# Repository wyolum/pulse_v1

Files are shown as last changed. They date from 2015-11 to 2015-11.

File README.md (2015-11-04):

# pulse_v1
Breathing LED lamp for Motorcycle using ATtiny
=======

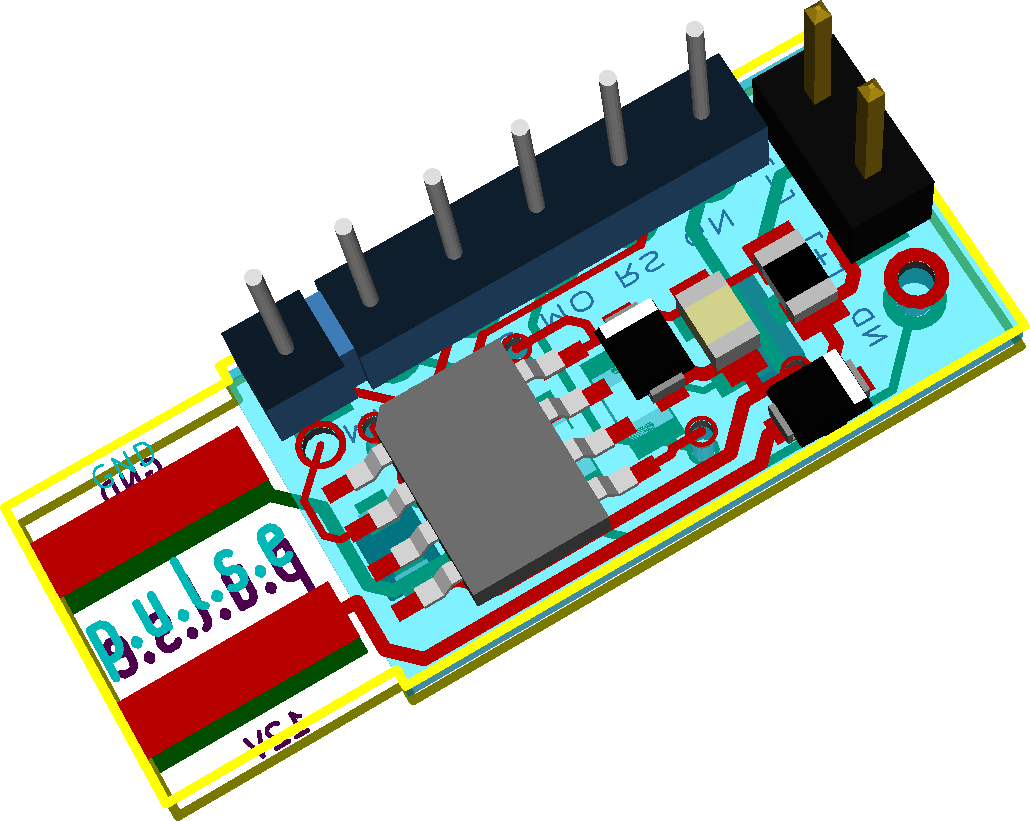
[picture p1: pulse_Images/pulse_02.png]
pulse_v1 top


License
-------
[CERN Open Hardware Licence v1.2 ]

[CERN Open Hardware Licence v1.2 ]:http://www.ohwr.org/attachments/2388/cern_ohl_v_1_2.txt

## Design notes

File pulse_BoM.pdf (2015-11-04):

BoM, for kit building assembly | 5.05 | 4.54
ref | value | MODULE | Manufacturer | Mfr. P/N | Vendor | Vendor P/N | NOTE1 | QTY | RATE | AMOUNT
C1 | 10n | c_0805 | Kemet | C0805C103K5RACTU | 399-1158-1-ND | Decoupling capacitor, Ceramic | 1 0.05 | 0.05
C2 | 100n | c_0805 | Kemet | C0805C104K3RACTU | 399-1168-1-ND | Decoupling capacitor, Ceramic | 1 0.07 | 0.07
D1 | Z5V1 | SOD323F | Fairchild Semiconductor | MM3Z5V1C | MM3Z5V1CCT-ND | input protection diode | 1 0.20 | 0.20
D2 | Z5V1 | SOD323F | Fairchild Semiconductor | MM3Z5V1C | MM3Z5V1CCT-ND | 5V regulation diode | 1 0.20 | 0.20
D3 | 1N4448WT | SOD523F | Fairchild Semiconductor | 1N4448WT | | 1N4448WTCT-ND | reverse polarity protection diode | 1 | 0.17 | 0.17
K2 | ISP | pin_strip_6b Sullins Connector Solutions PREC040SAAN-RC | S1012EC-40-ND | Header, Male, 8x1 – K2+P1+P3 | 1 | 0.51 | 0.00
P1 | LAMP | pin_strip_2 | -- | -- | -- | -- | PCB edge fits Lamp T10 connector | 1 0.00 | 0.00
P2 | 12V | Header_12V -- | -- | -- | -- | see K2 | 1 0.00 | 0.00
P3 | ND | Pad01 | -- | -- | -- | -- | see K2 | 1 0.00 | 0.00
PB3 ND | Pad01 | -- | -- | -- | -- | breakout pad | 1 0.00 | 0.00
PCB1 PCB | PCB | seeed | -- | -- | -- | -- | 1 | 2.38 | 2.38
Q1 | 2N7000 | SOT23-3 | Toshiba | SSM3K7002BF(T5L,F) | SSM3K7002BF(T5LF)CT-ND | 1 0.35 | 0.35
R1 | 4K7 | r_0805 | Stackpole Electronics Inc | RMCF0805JT4K70 | RMCF0805JT4K70CT-ND | 1 0.03 | 0.03
R2 | 4K7 | r_0805 | Stackpole Electronics Inc | RMCF0805JT4K70 | RMCF0805JT4K70CT-ND | 1 0.03 | 0.03
R3 | 2k2 | r_0805 | Stackpole Electronics Inc | RMCF0805JT2K20 | RMCF0805JT2K20CT-ND | 1 0.03 | 0.03
U1 | ATTINY45-20SUSO8E | Atmel | ATTINY45-20SU | ATTINY45-20SU-ND | 1 | 1.03 | 1.03

DigiKey (http://www.digikey.com/product-detail/en/C0805C103K5RACTU/399-1158-1-ND/411433)
DigiKey (http://www.digikey.com/product-detail/en/C0805C104K3RACTU/399-1168-1-ND/411443)
DigiKey
DigiKey (http://www.digikey.com/product-detail/en/MM3Z5V1C/MM3Z5V1CCT-ND/1626900)
DigiKey (http://www.digikey.com/product-detail/en/1N4448WT/1N4448WTCT-ND/1966596)
DigiKey (http://www.digikey.com/product-detail/en/PREC040SAAN-RC/S1012EC-40-ND/2774814)

DigiKey (http://www.digikey.com/product-detail/en/SSM3K7002BF(T5L,F)/SSM3K7002BF(T5LF)CT-ND/969393)
DigiKey
DigiKey (http://www.digikey.com/product-detail/en/RMCF0805JT4K70/RMCF0805JT4K70CT-ND/1942570)
DigiKey (http://www.digikey.com/product-detail/en/RMCF0805JT2K20/RMCF0805JT2K20CT-ND/1942563)
DigiKey (http://www.digikey.com/product-detail/en/ATTINY45-20SU/ATTINY45-20SU-ND/735466)

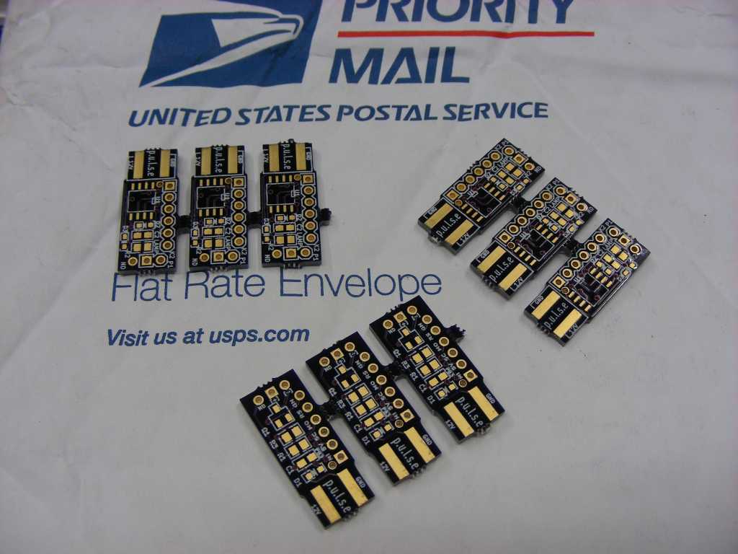
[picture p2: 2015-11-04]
pulse_Images/pulse_03.jpg

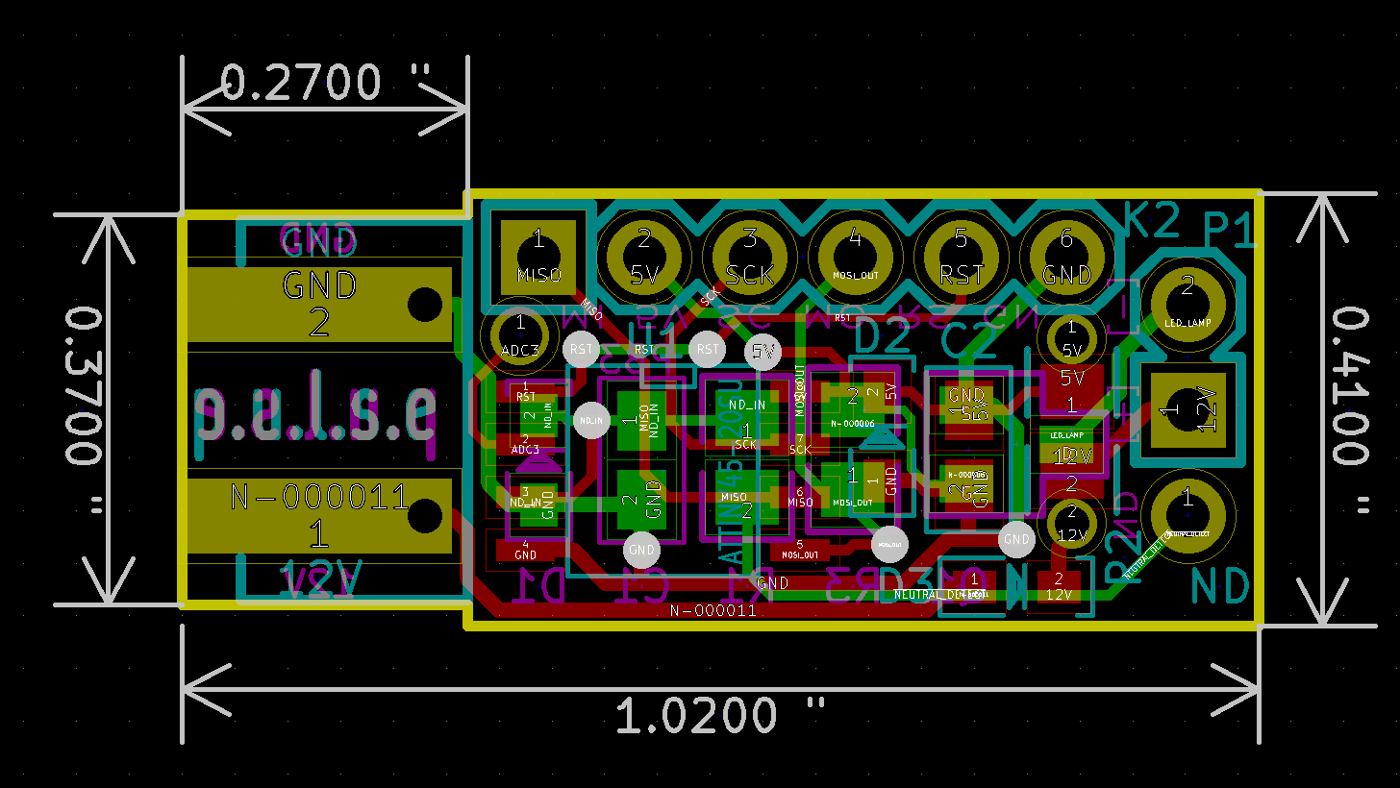
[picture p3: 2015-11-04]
pulse_Images/pulse_01.png

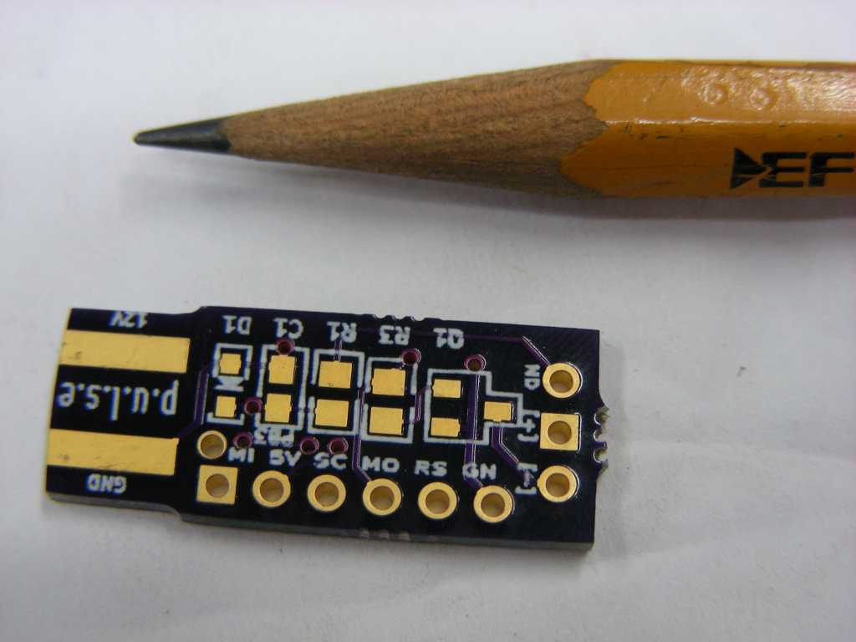
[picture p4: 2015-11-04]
pulse_Images/pulse_05.jpg

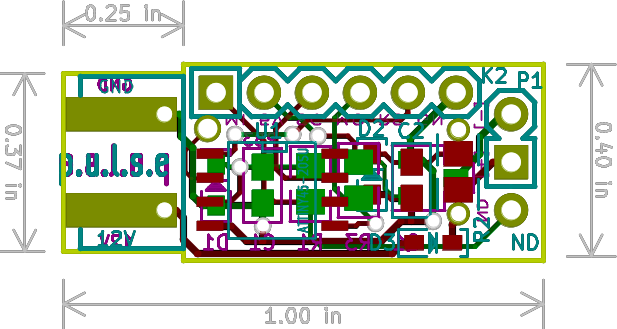
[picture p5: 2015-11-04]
pulse_Images/pulse_v1_PCB_stack.png

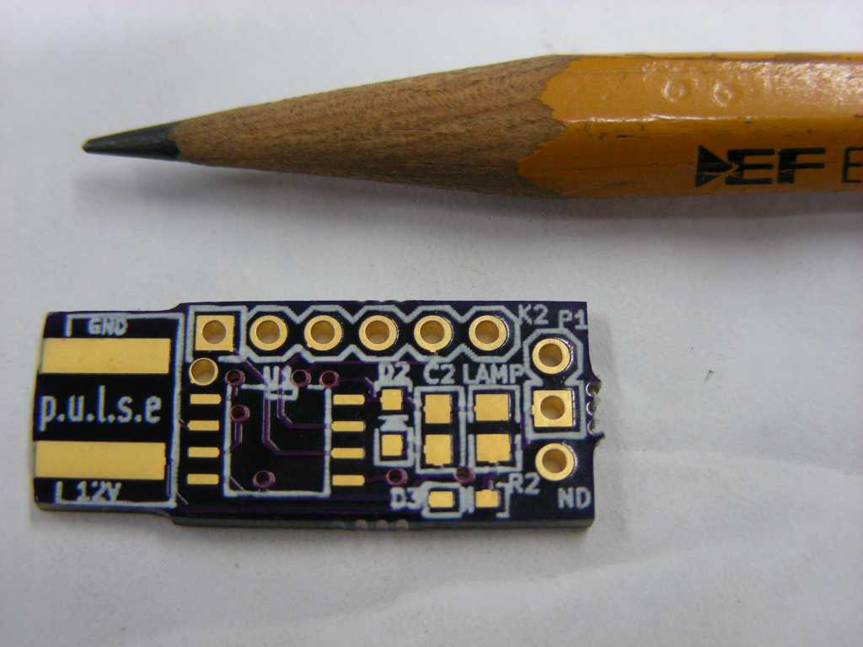
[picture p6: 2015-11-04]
pulse_Images/pulse_04.jpg

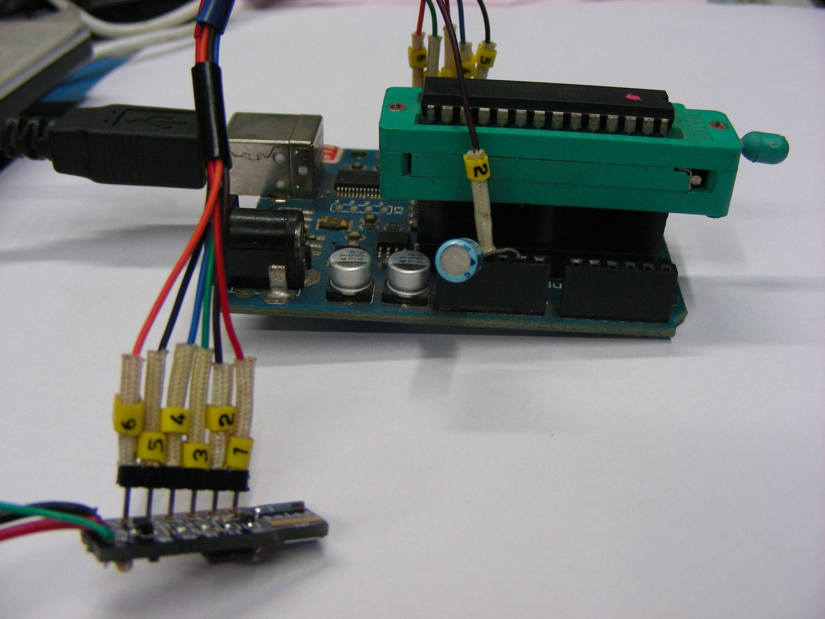
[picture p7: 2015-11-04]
pulse_Images/pulse_09.jpg

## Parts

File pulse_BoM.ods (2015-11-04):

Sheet: Final_BoM
BoM, for kit building assembly |  |  |  |  |  |  |  |  | 5.05 | 4.54
ref | value | MODULE | Manufacturer | Mfr. P/N | Vendor | Vendor P/N | NOTE1 | QTY | RATE | AMOUNT
C1 | 10n | c_0805 | Kemet | C0805C103K5RACTU | DigiKey (http://www.digikey.com/product-detail/en/C0805C103K5RACTU/399-1158-1-ND/411433) | 399-1158-1-ND | Decoupling capacitor, Ceramic | 1 | 0.05 | 0.05
C2 | 100n | c_0805 | Kemet | C0805C104K3RACTU | DigiKey (http://www.digikey.com/product-detail/en/C0805C104K3RACTU/399-1168-1-ND/411443) | 399-1168-1-ND | Decoupling capacitor, Ceramic | 1 | 0.07 | 0.07
D1 | Z5V1 | SOD323F | Fairchild Semiconductor | MM3Z5V1C | DigiKey (http://www.digikey.com/product-detail/en/MM3Z5V1C/MM3Z5V1CCT-ND/1626900) | MM3Z5V1CCT-ND | input protection diode | 1 | 0.20 | 0.20
D2 | Z5V1 | SOD323F | Fairchild Semiconductor | MM3Z5V1C | DigiKey (http://www.digikey.com/product-detail/en/MM3Z5V1C/MM3Z5V1CCT-ND/1626900) | MM3Z5V1CCT-ND | 5V regulation diode | 1 | 0.20 | 0.20
D3 | 1N4448WT | SOD523F | Fairchild Semiconductor | 1N4448WT | DigiKey (http://www.digikey.com/product-detail/en/1N4448WT/1N4448WTCT-ND/1966596) | 1N4448WTCT-ND | reverse polarity protection diode | 1 | 0.17 | 0.17
K2 | ISP | pin_strip_6b | Sullins Connector Solutions | PREC040SAAN-RC | DigiKey (http://www.digikey.com/product-detail/en/PREC040SAAN-RC/S1012EC-40-ND/2774814) | S1012EC-40-ND | Header, Male, 8x1 – K2+P1+P3 | 1 | 0.51 | 0.00
P1 | LAMP | pin_strip_2 | -- | -- | -- | -- | PCB edge fits Lamp T10 connector | 1 | 0.00 | 0.00
P2 | 12V | Header_12V | -- | -- | -- | -- | see K2 | 1 | 0.00 | 0.00
P3 | ND | Pad01 | -- | -- | -- | -- | see K2 | 1 | 0.00 | 0.00
PB3 | ND | Pad01 | -- | -- | -- | -- | breakout pad | 1 | 0.00 | 0.00
PCB1 | PCB | PCB | seeed | -- | -- | -- | -- | 1 | 2.38 | 2.38
Q1 | 2N7000 | SOT23-3 | Toshiba | SSM3K7002BF(T5L,F) | DigiKey (http://www.digikey.com/product-detail/en/SSM3K7002BF(T5L,F)/SSM3K7002BF(T5LF)CT-ND/969393) | SSM3K7002BF(T5LF)CT-ND |  | 1 | 0.35 | 0.35
R1 | 4K7 | r_0805 | Stackpole Electronics Inc | RMCF0805JT4K70 | DigiKey (http://www.digikey.com/product-detail/en/RMCF0805JT4K70/RMCF0805JT4K70CT-ND/1942570) | RMCF0805JT4K70CT-ND |  | 1 | 0.03 | 0.03
R2 | 4K7 | r_0805 | Stackpole Electronics Inc | RMCF0805JT4K70 | DigiKey (http://www.digikey.com/product-detail/en/RMCF0805JT4K70/RMCF0805JT4K70CT-ND/1942570) | RMCF0805JT4K70CT-ND |  | 1 | 0.03 | 0.03
R3 | 2k2 | r_0805 | Stackpole Electronics Inc | RMCF0805JT2K20 | DigiKey (http://www.digikey.com/product-detail/en/RMCF0805JT2K20/RMCF0805JT2K20CT-ND/1942563) | RMCF0805JT2K20CT-ND |  | 1 | 0.03 | 0.03
U1 | ATTINY45-20SU | SO8E | Atmel | ATTINY45-20SU | DigiKey (http://www.digikey.com/product-detail/en/ATTINY45-20SU/ATTINY45-20SU-ND/735466) | ATTINY45-20SU-ND |  | 1 | 1.03 | 1.03

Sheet: BoM_SCH
ref | value | footprint | Field1 | Field2 | Field3 | Field4 | Field5 | Field6 | Field7 | Field8
C1 | 10n | c_0805
C2 | 100n | c_0805
D1 | Z5V1 | SOD323F
D2 | Z5V1 | SOD323F
D3 | 1N4448WT | SOD523F
K2 | ISP | pin_strip_6b
P1 | LAMP | pin_strip_2
P2 | 12V | Header_12V
P3 | ND | Pad01
PB3 | ND | Pad01
PCB1 | PCB | PCB
Q1 | 2N7000 | SOT23-3
R1 | 4K7 | r_0805
R2 | 4K7 | r_0805
R3 | 2k2 | r_0805
U1 | ATTINY45-20SU | SO8E

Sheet: BoM_PCB
Id | Designator | Package | Quantity | Designation | Supplier and ref
1 | C1 | c_0805 | 1 | 10n
2 | C2 | c_0805 | 1 | 100n
3 | D1,D2 | SOD323F | 2 | Z5V1
4 | D3 | SOD523F | 1 | 1N4448WT
5 | K2 | pin_strip_6b | 1 | ISP
6 | P1 | pin_strip_2 | 1 | LAMP
7 | P2 | Header_12V | 1 | 12V
8 | P3,PB3 | Pad01 | 1 | ND
9 | PCB1 | PCB | 1 | PCB
10 | Q1 | SOT23-3 | 1 | 2N7000
11 | R1,R2 | r_0805 | 2 | 4K7
12 | R3 | r_0805 | 1 | 2k2
13 | U1 | SO8E | 1 | ATTINY45-20SU

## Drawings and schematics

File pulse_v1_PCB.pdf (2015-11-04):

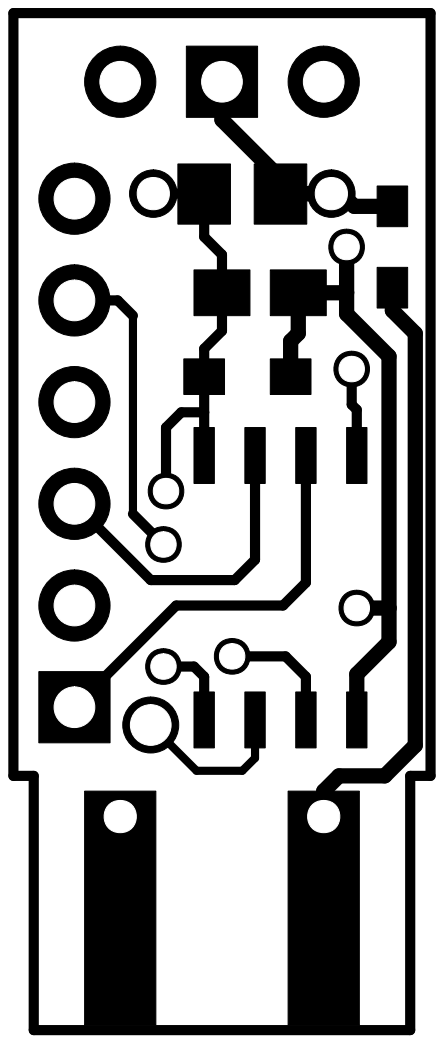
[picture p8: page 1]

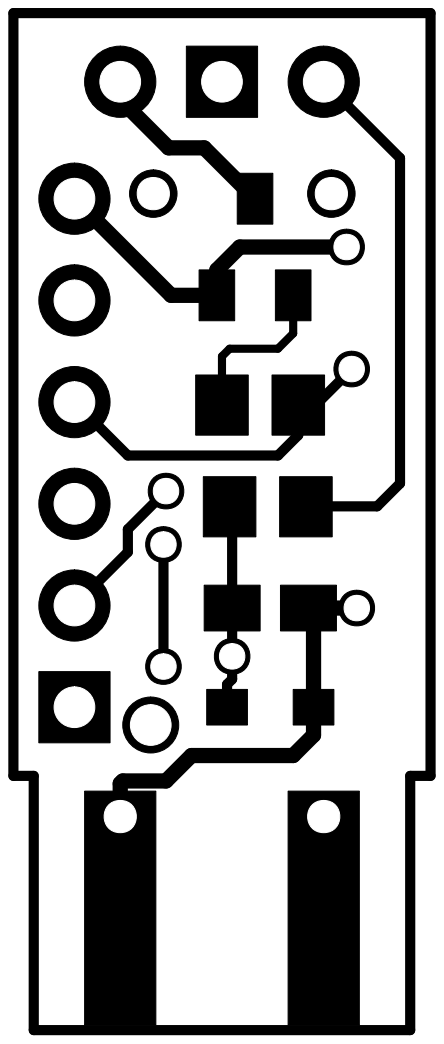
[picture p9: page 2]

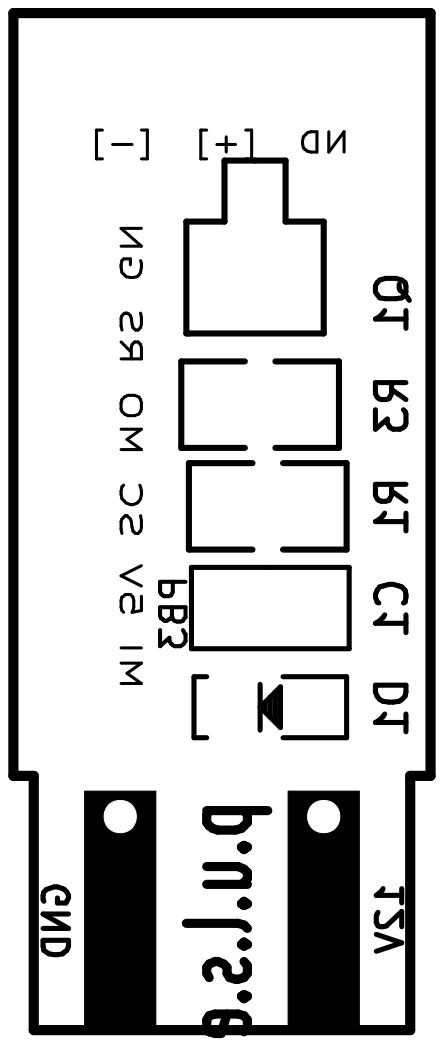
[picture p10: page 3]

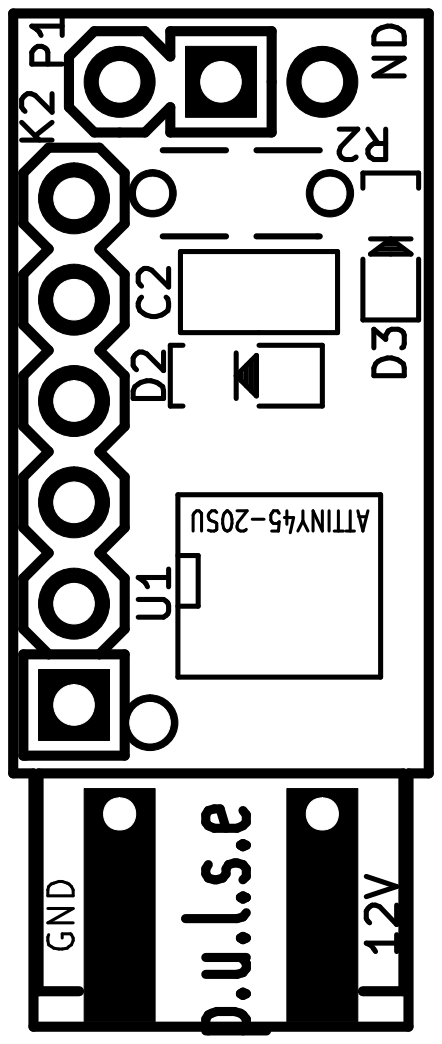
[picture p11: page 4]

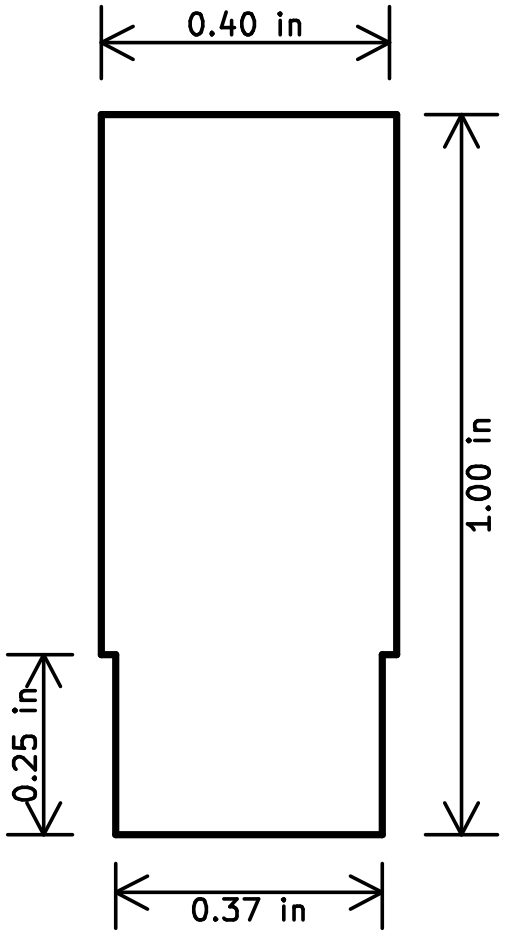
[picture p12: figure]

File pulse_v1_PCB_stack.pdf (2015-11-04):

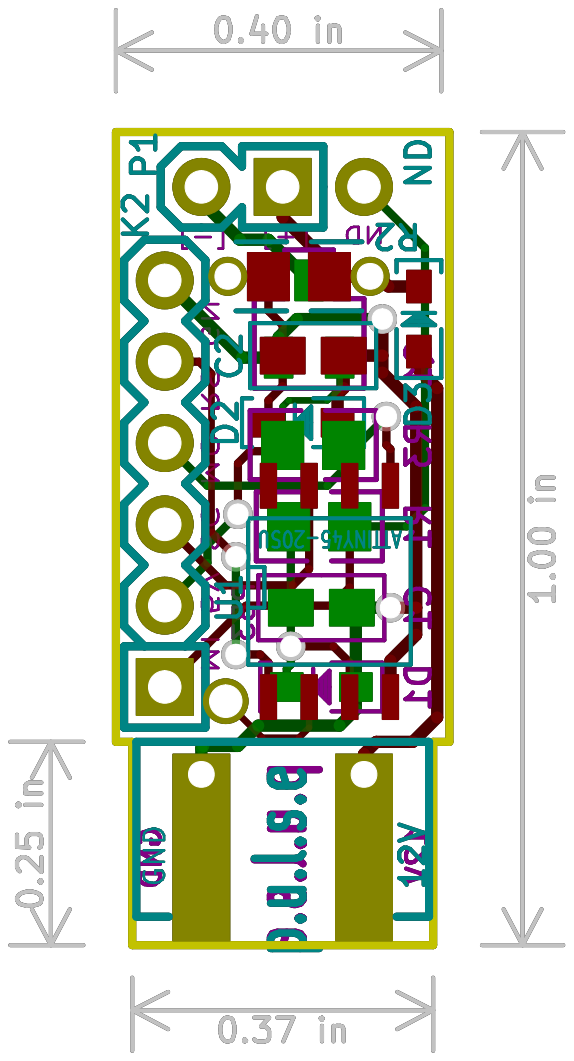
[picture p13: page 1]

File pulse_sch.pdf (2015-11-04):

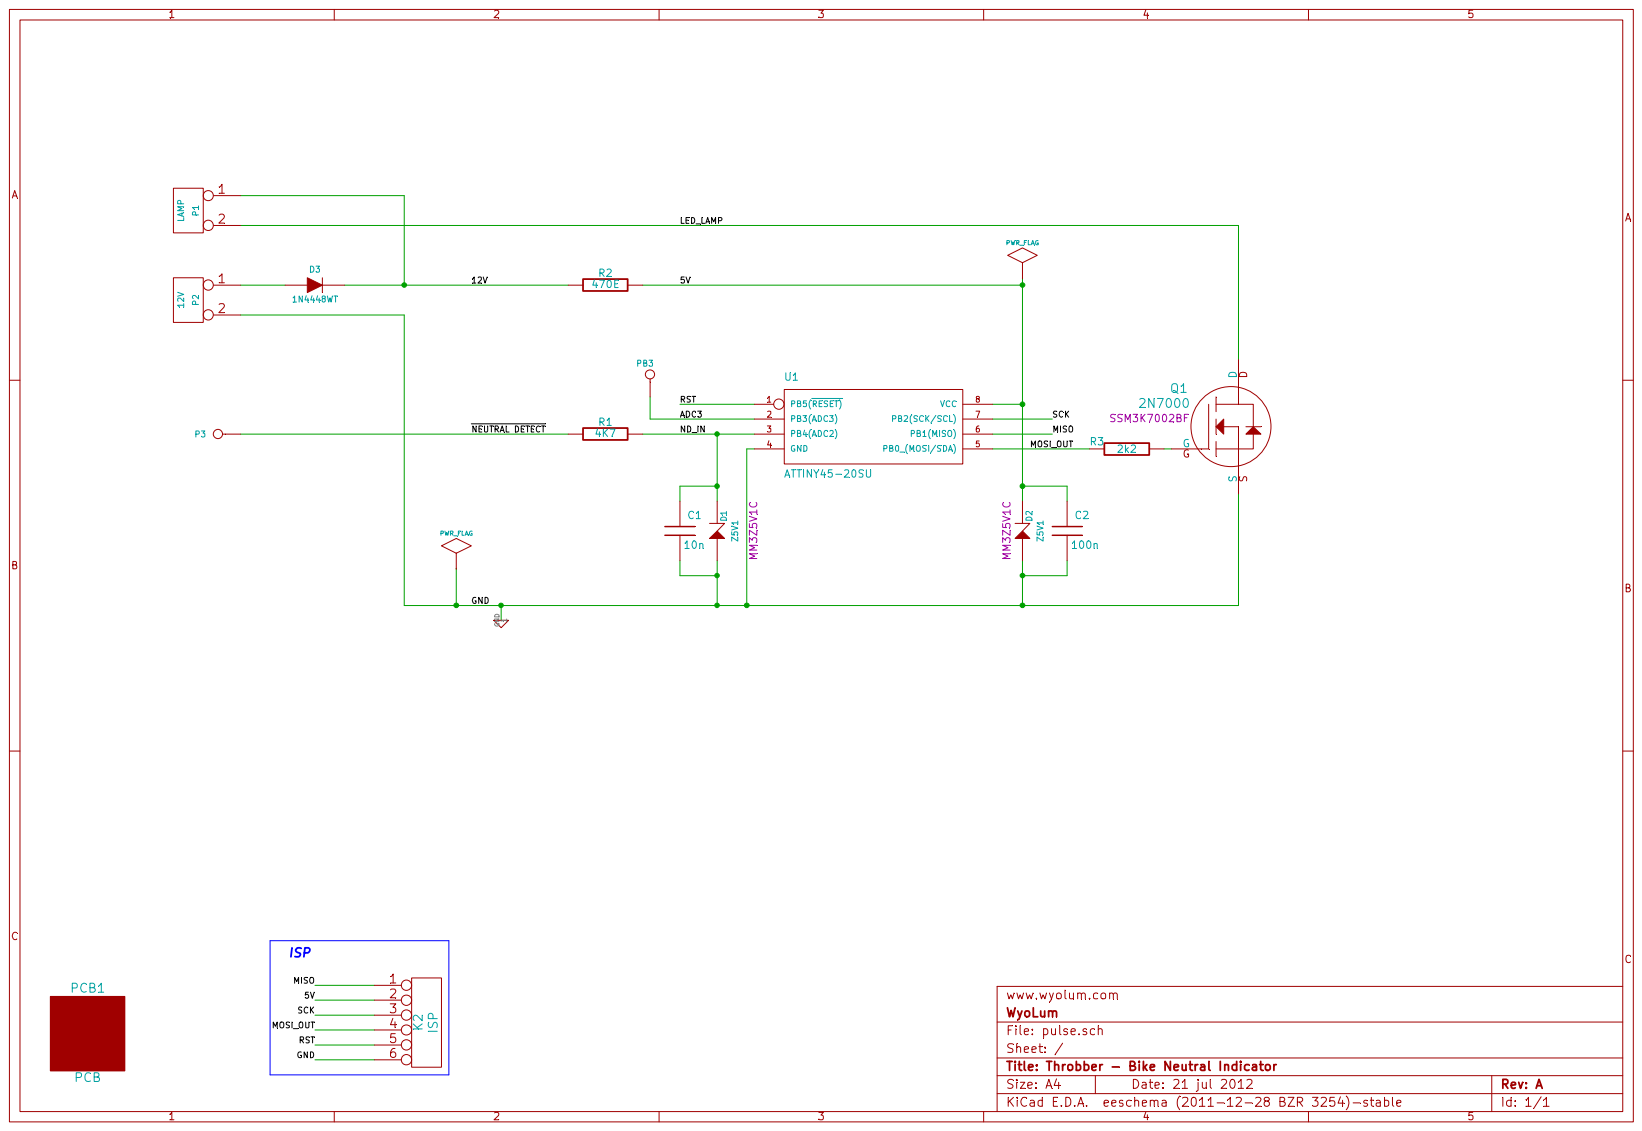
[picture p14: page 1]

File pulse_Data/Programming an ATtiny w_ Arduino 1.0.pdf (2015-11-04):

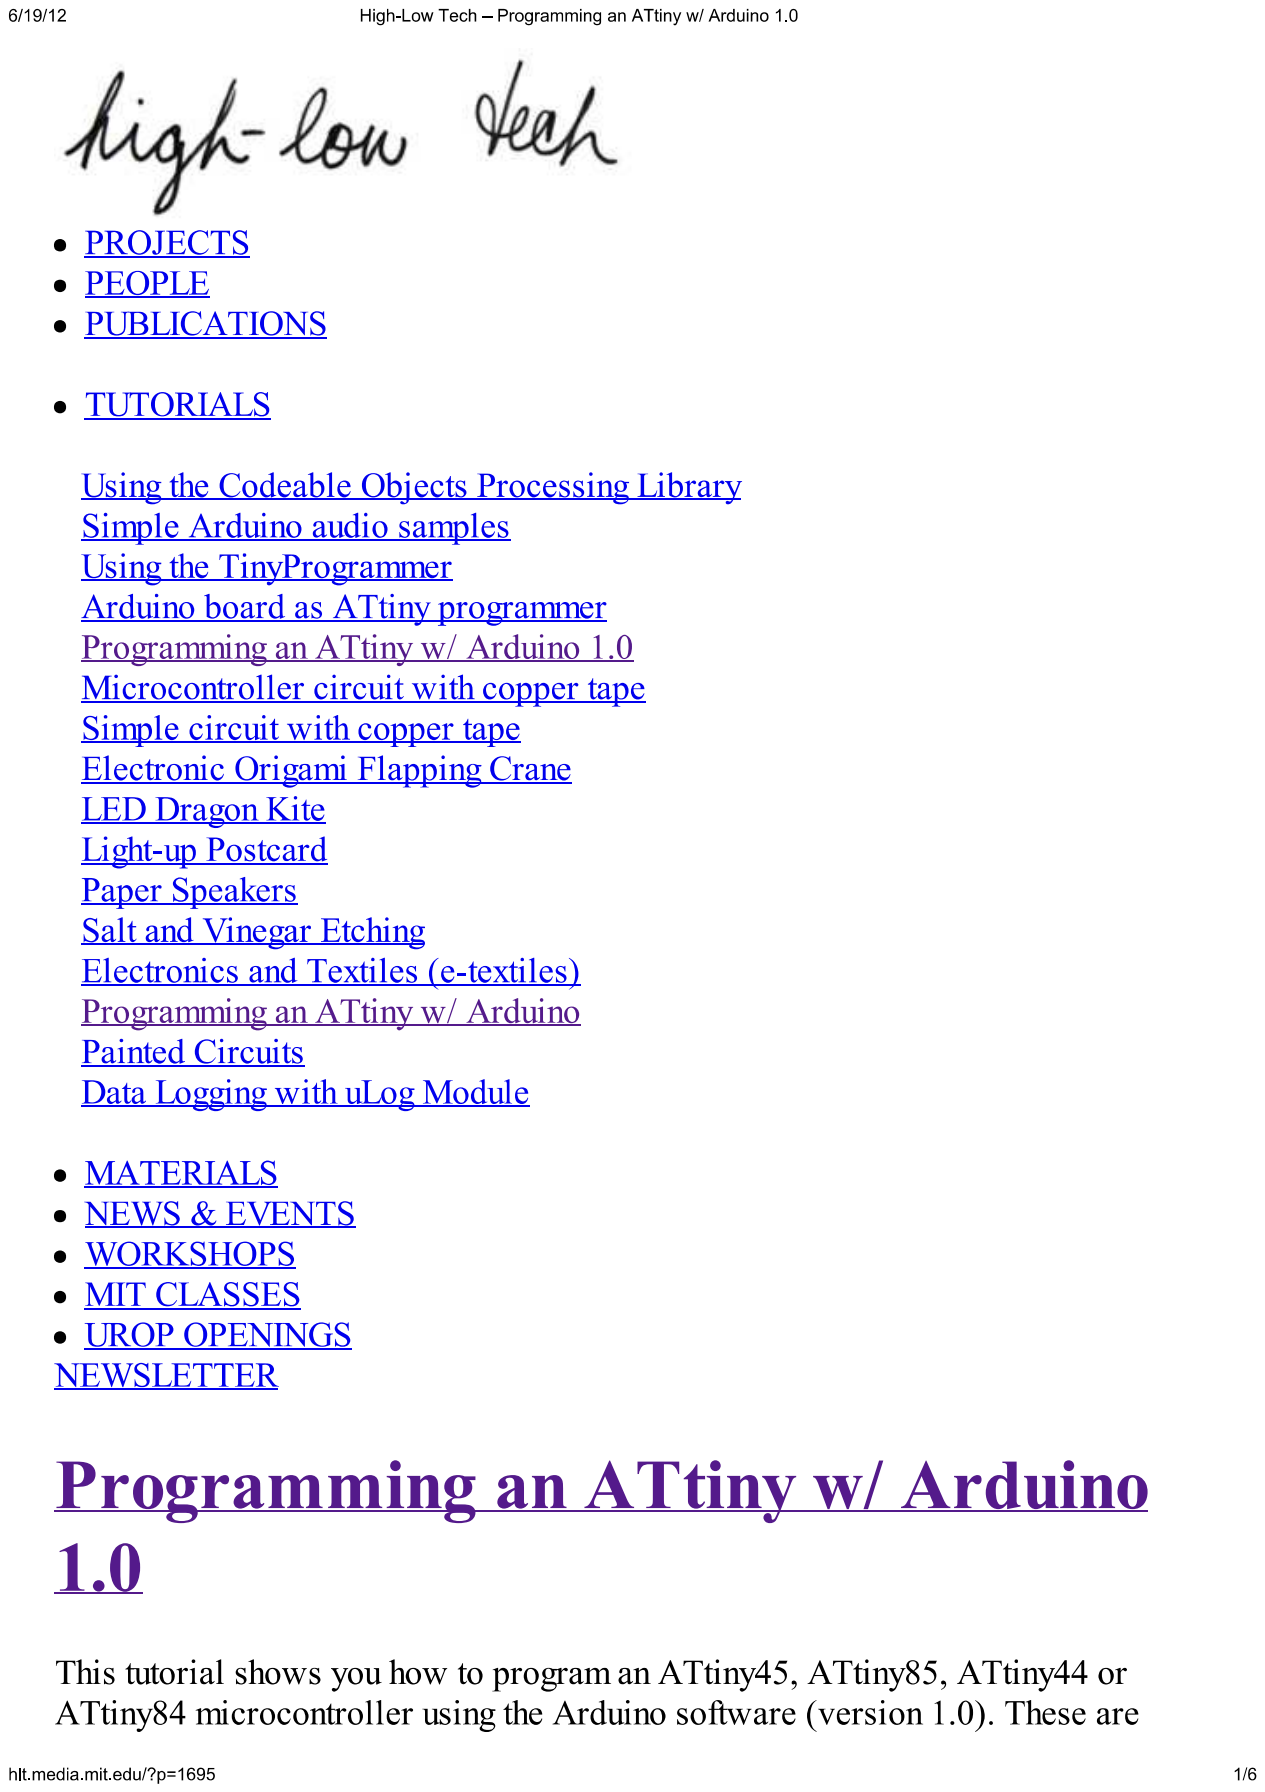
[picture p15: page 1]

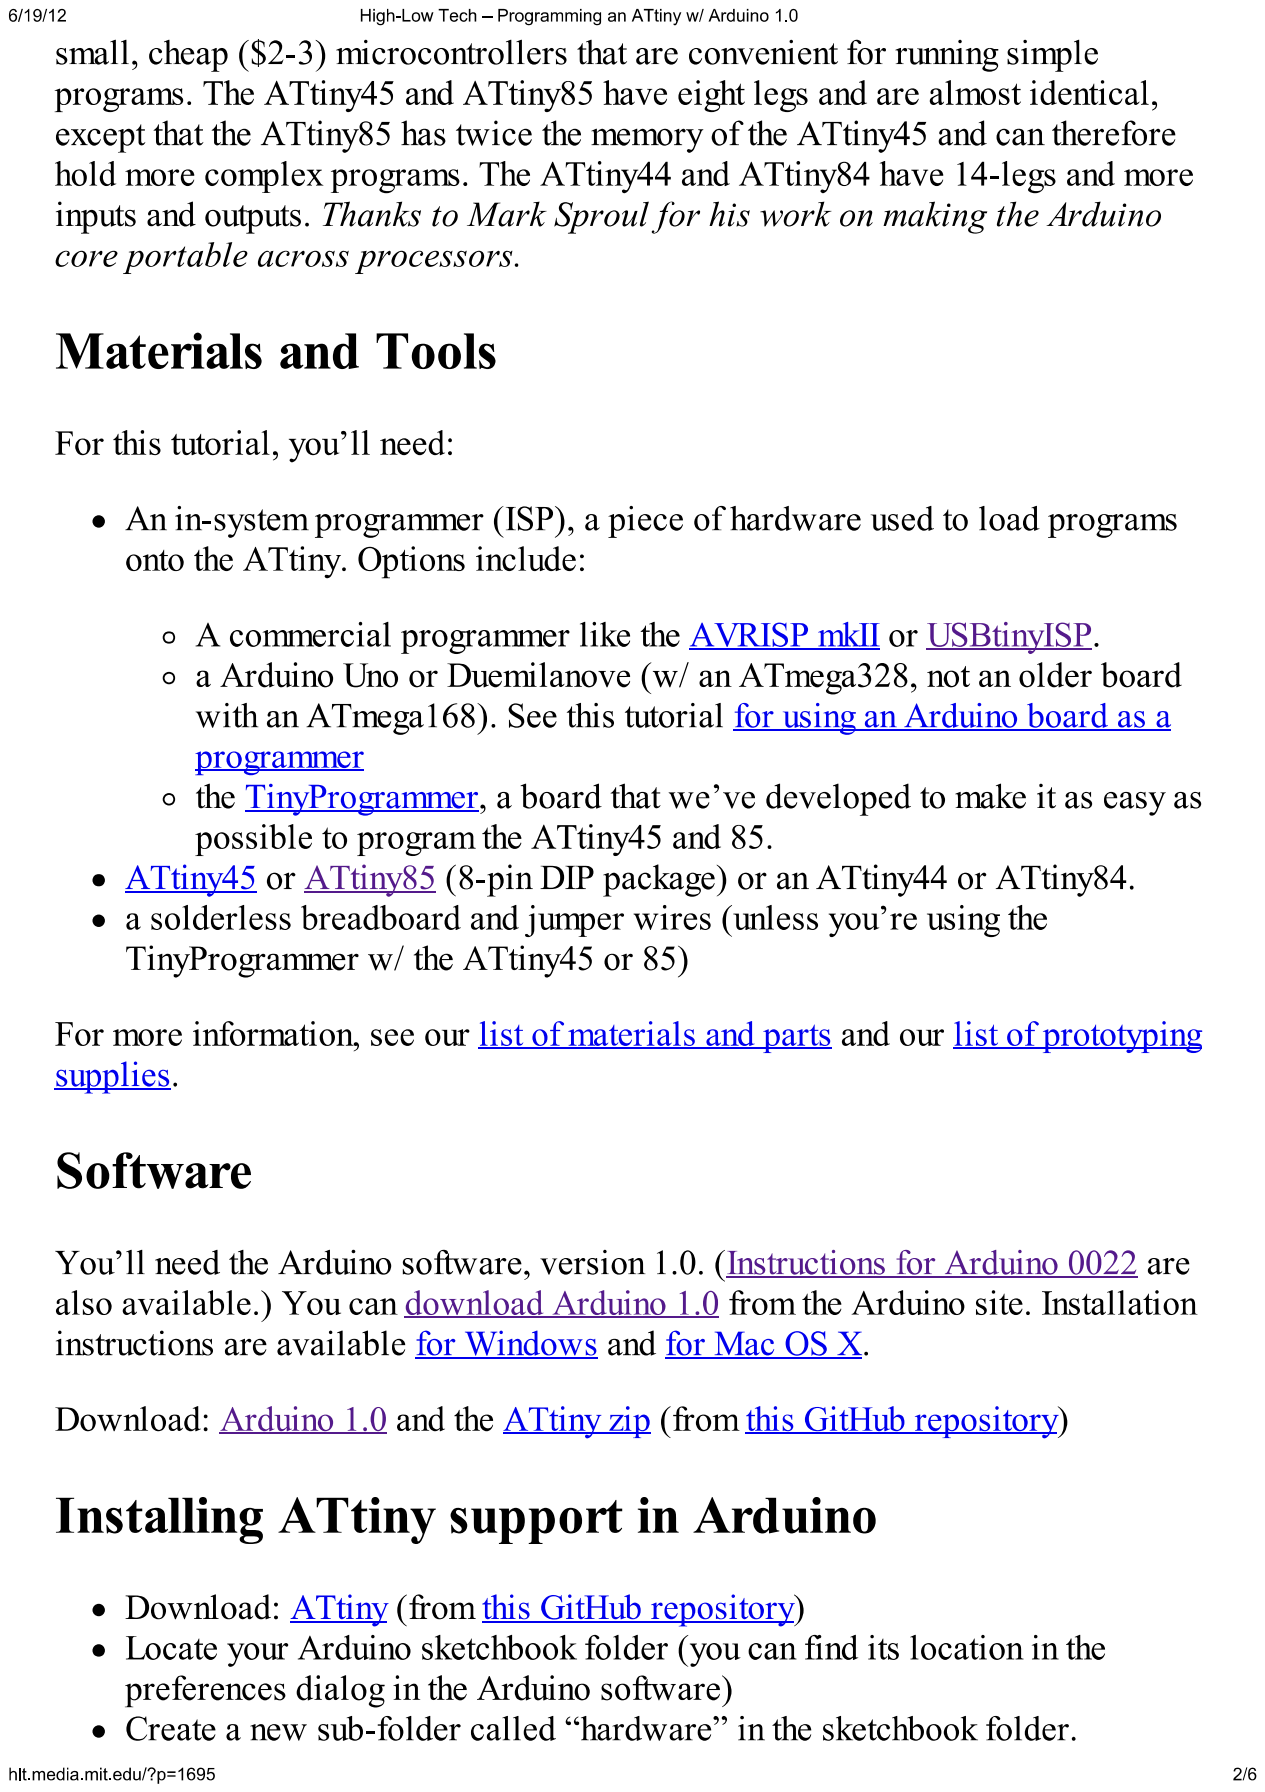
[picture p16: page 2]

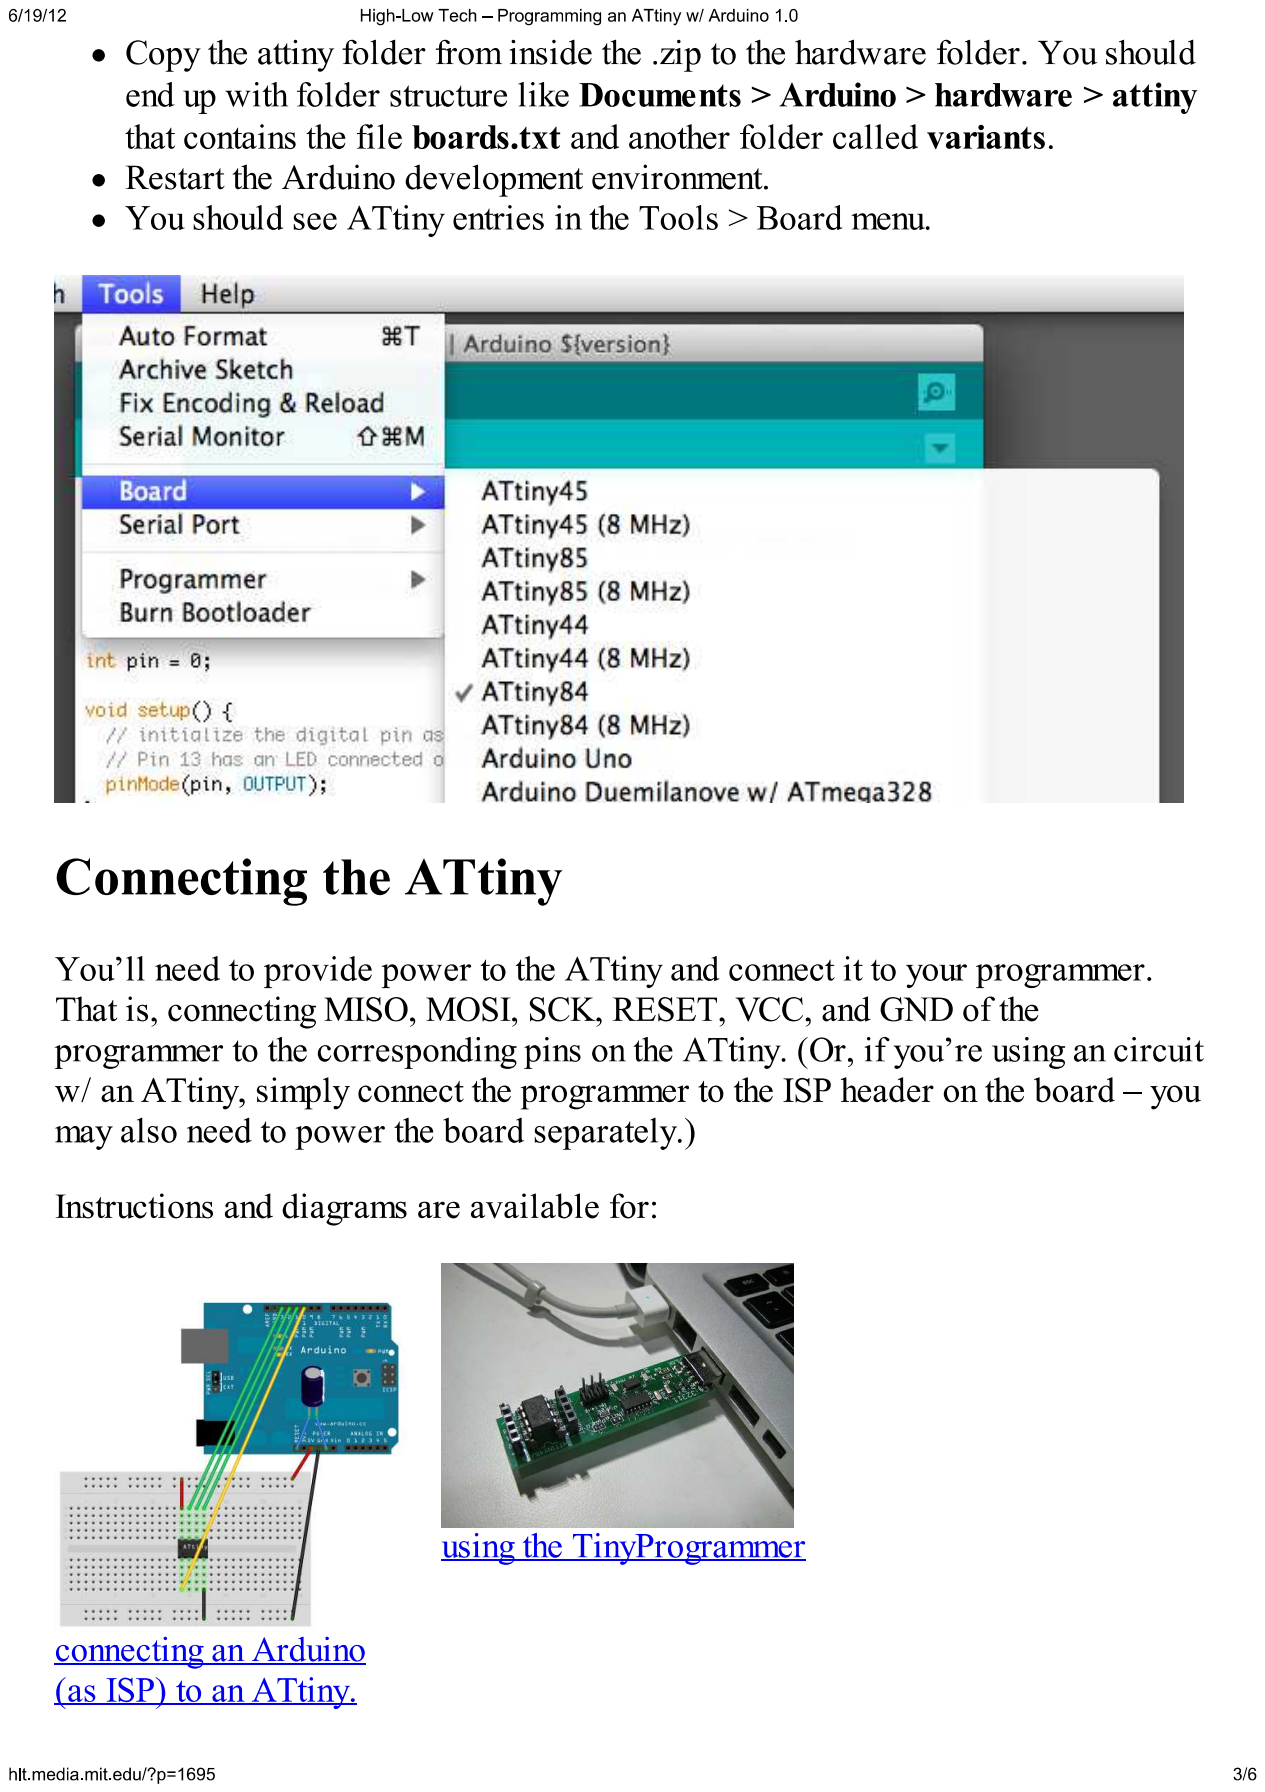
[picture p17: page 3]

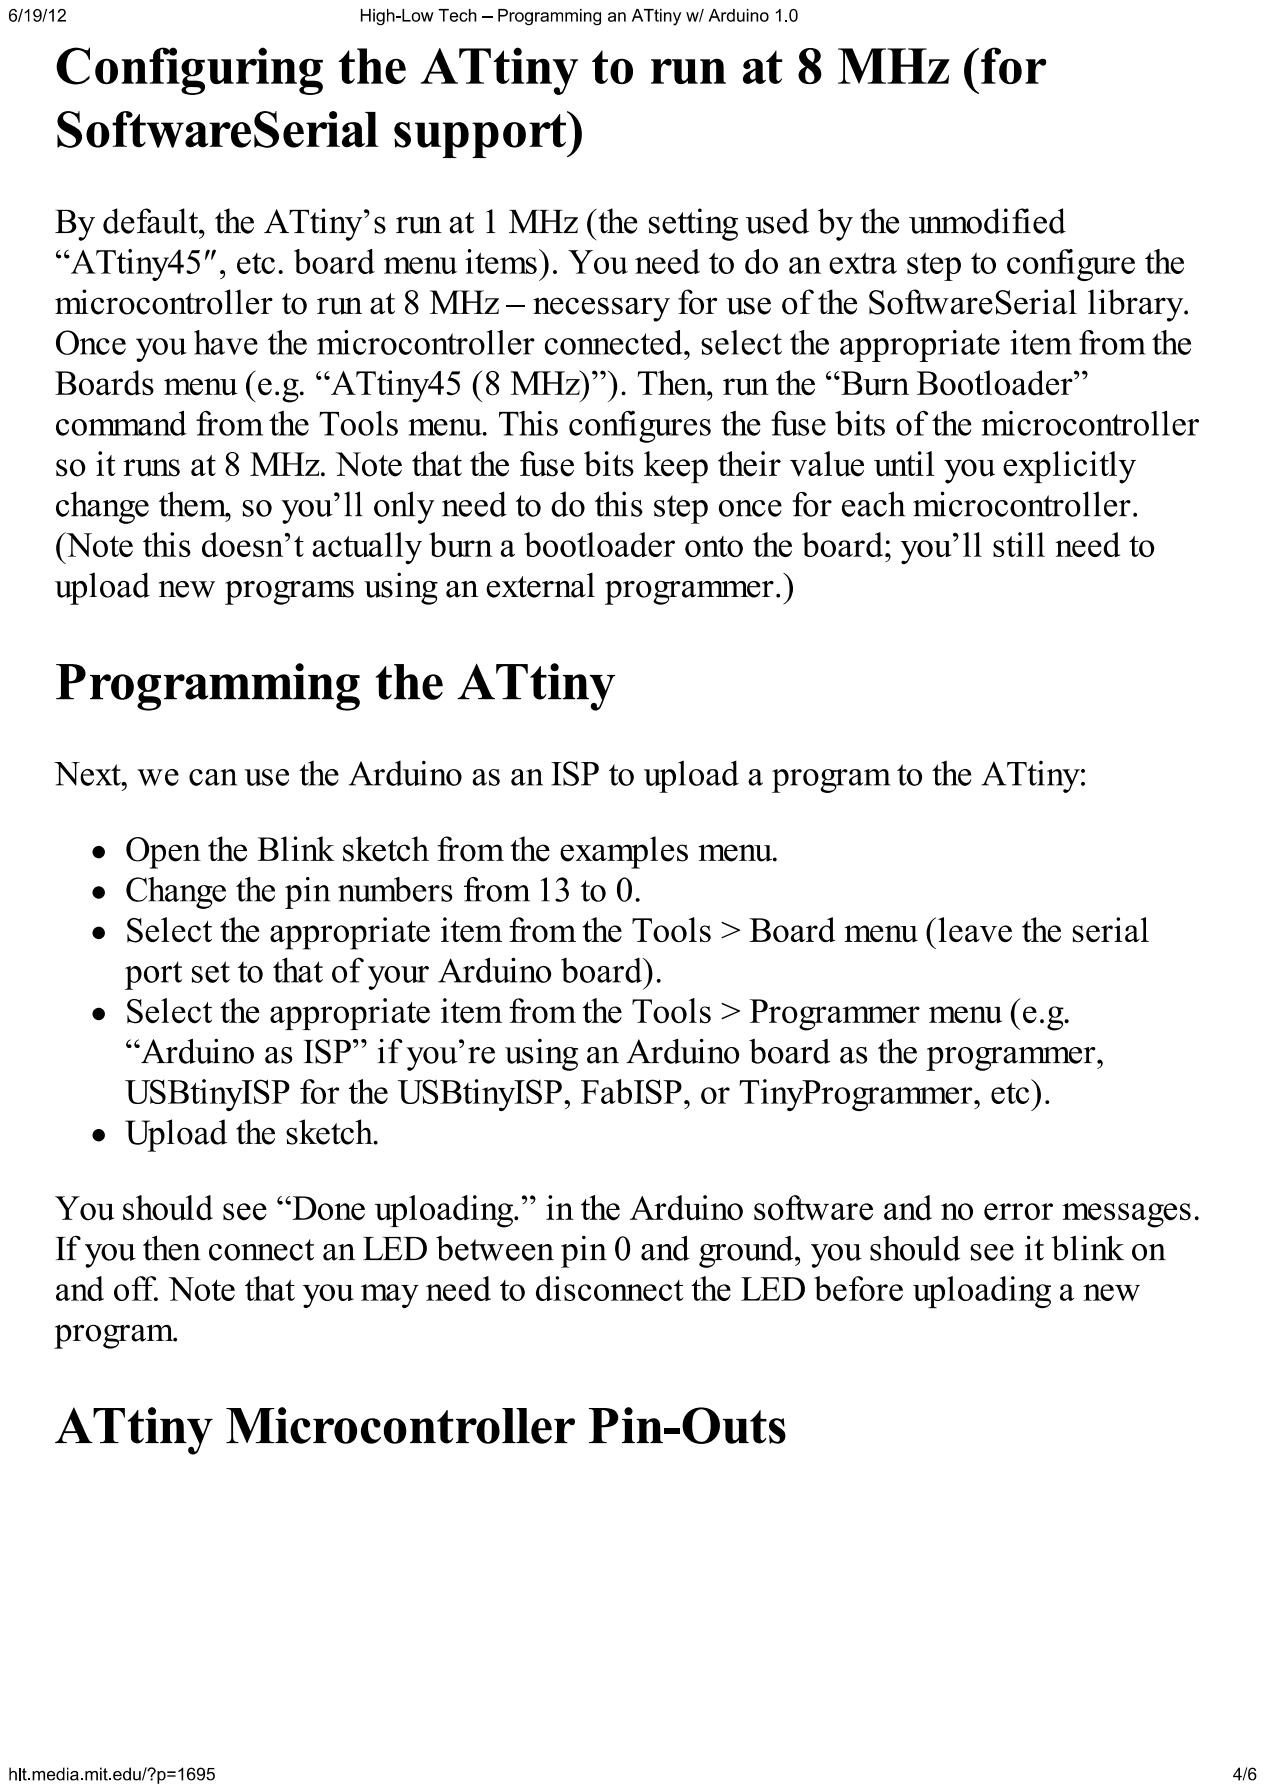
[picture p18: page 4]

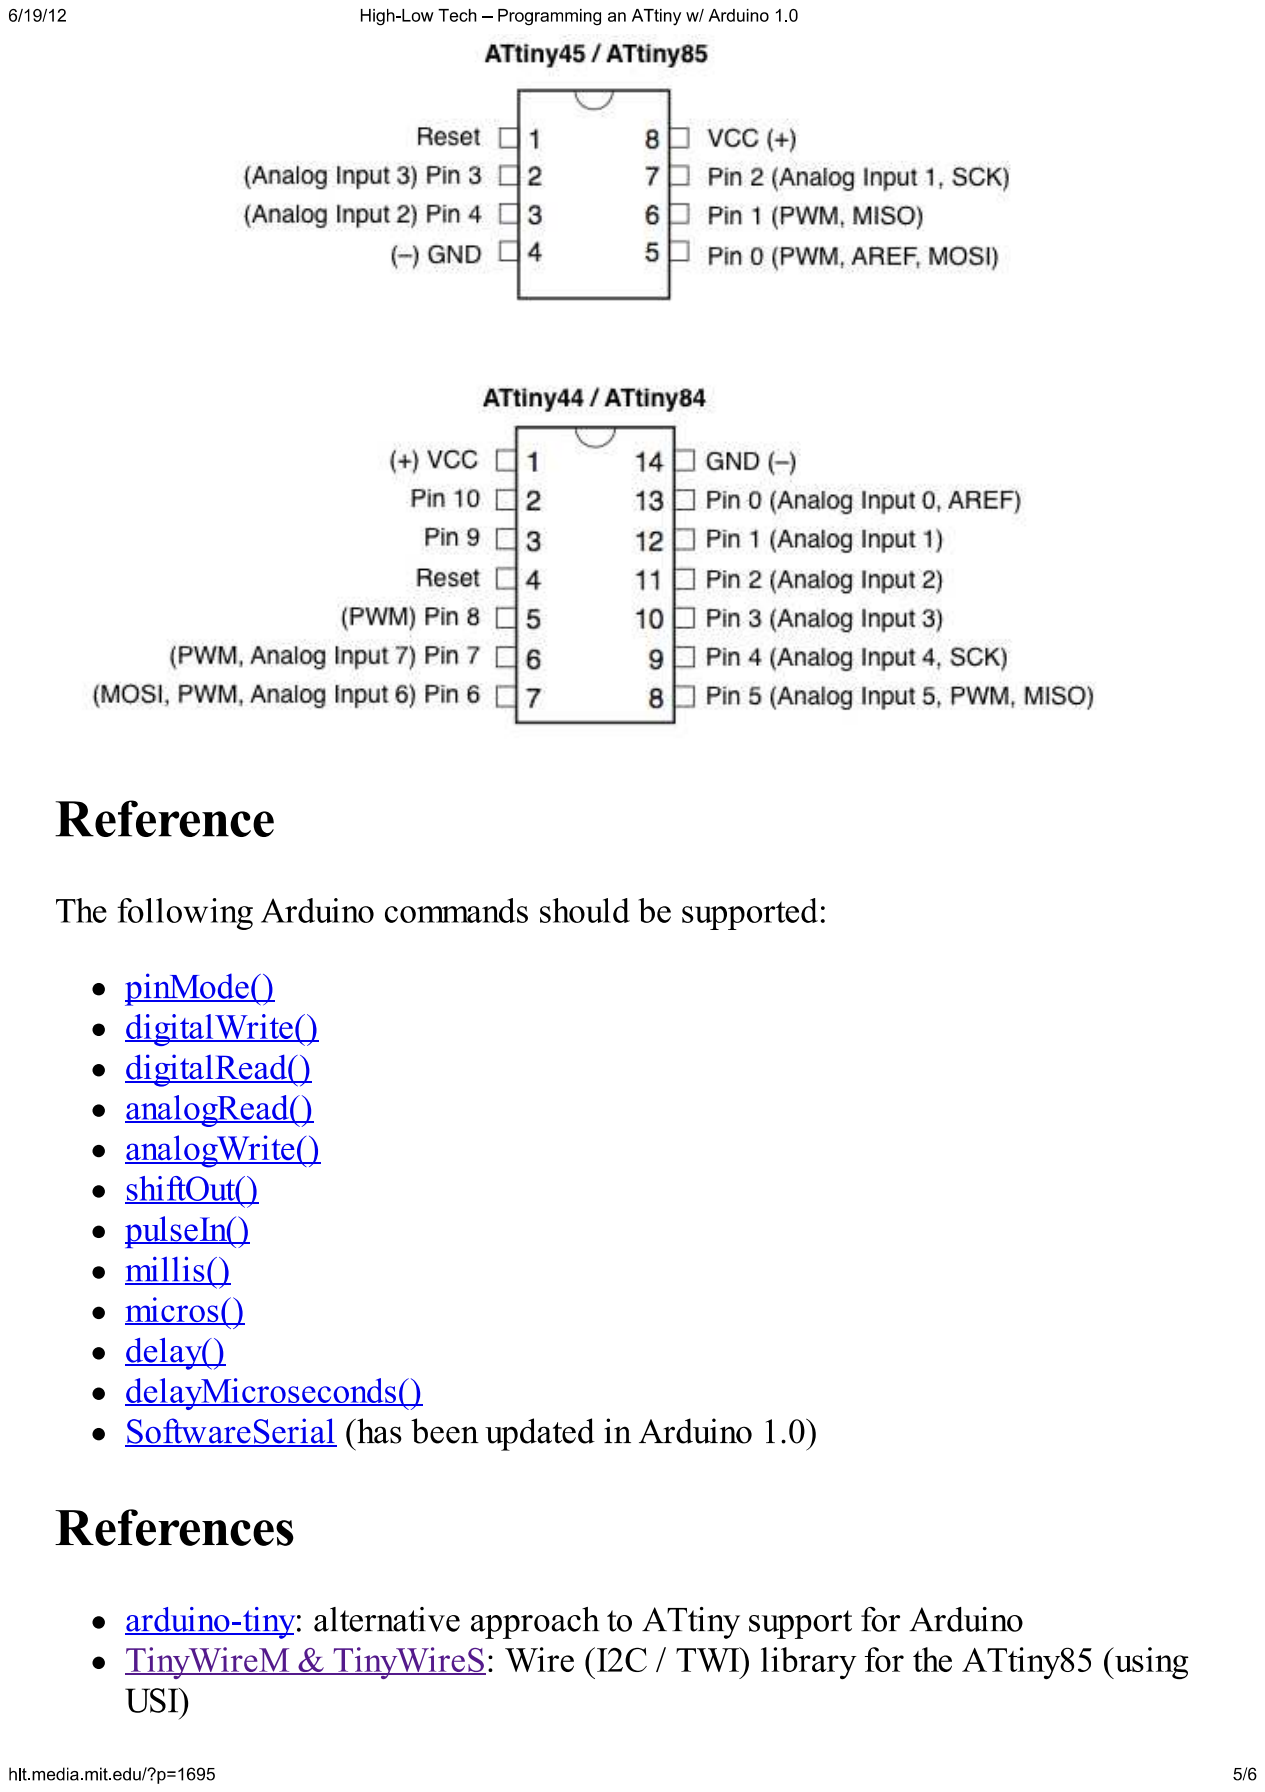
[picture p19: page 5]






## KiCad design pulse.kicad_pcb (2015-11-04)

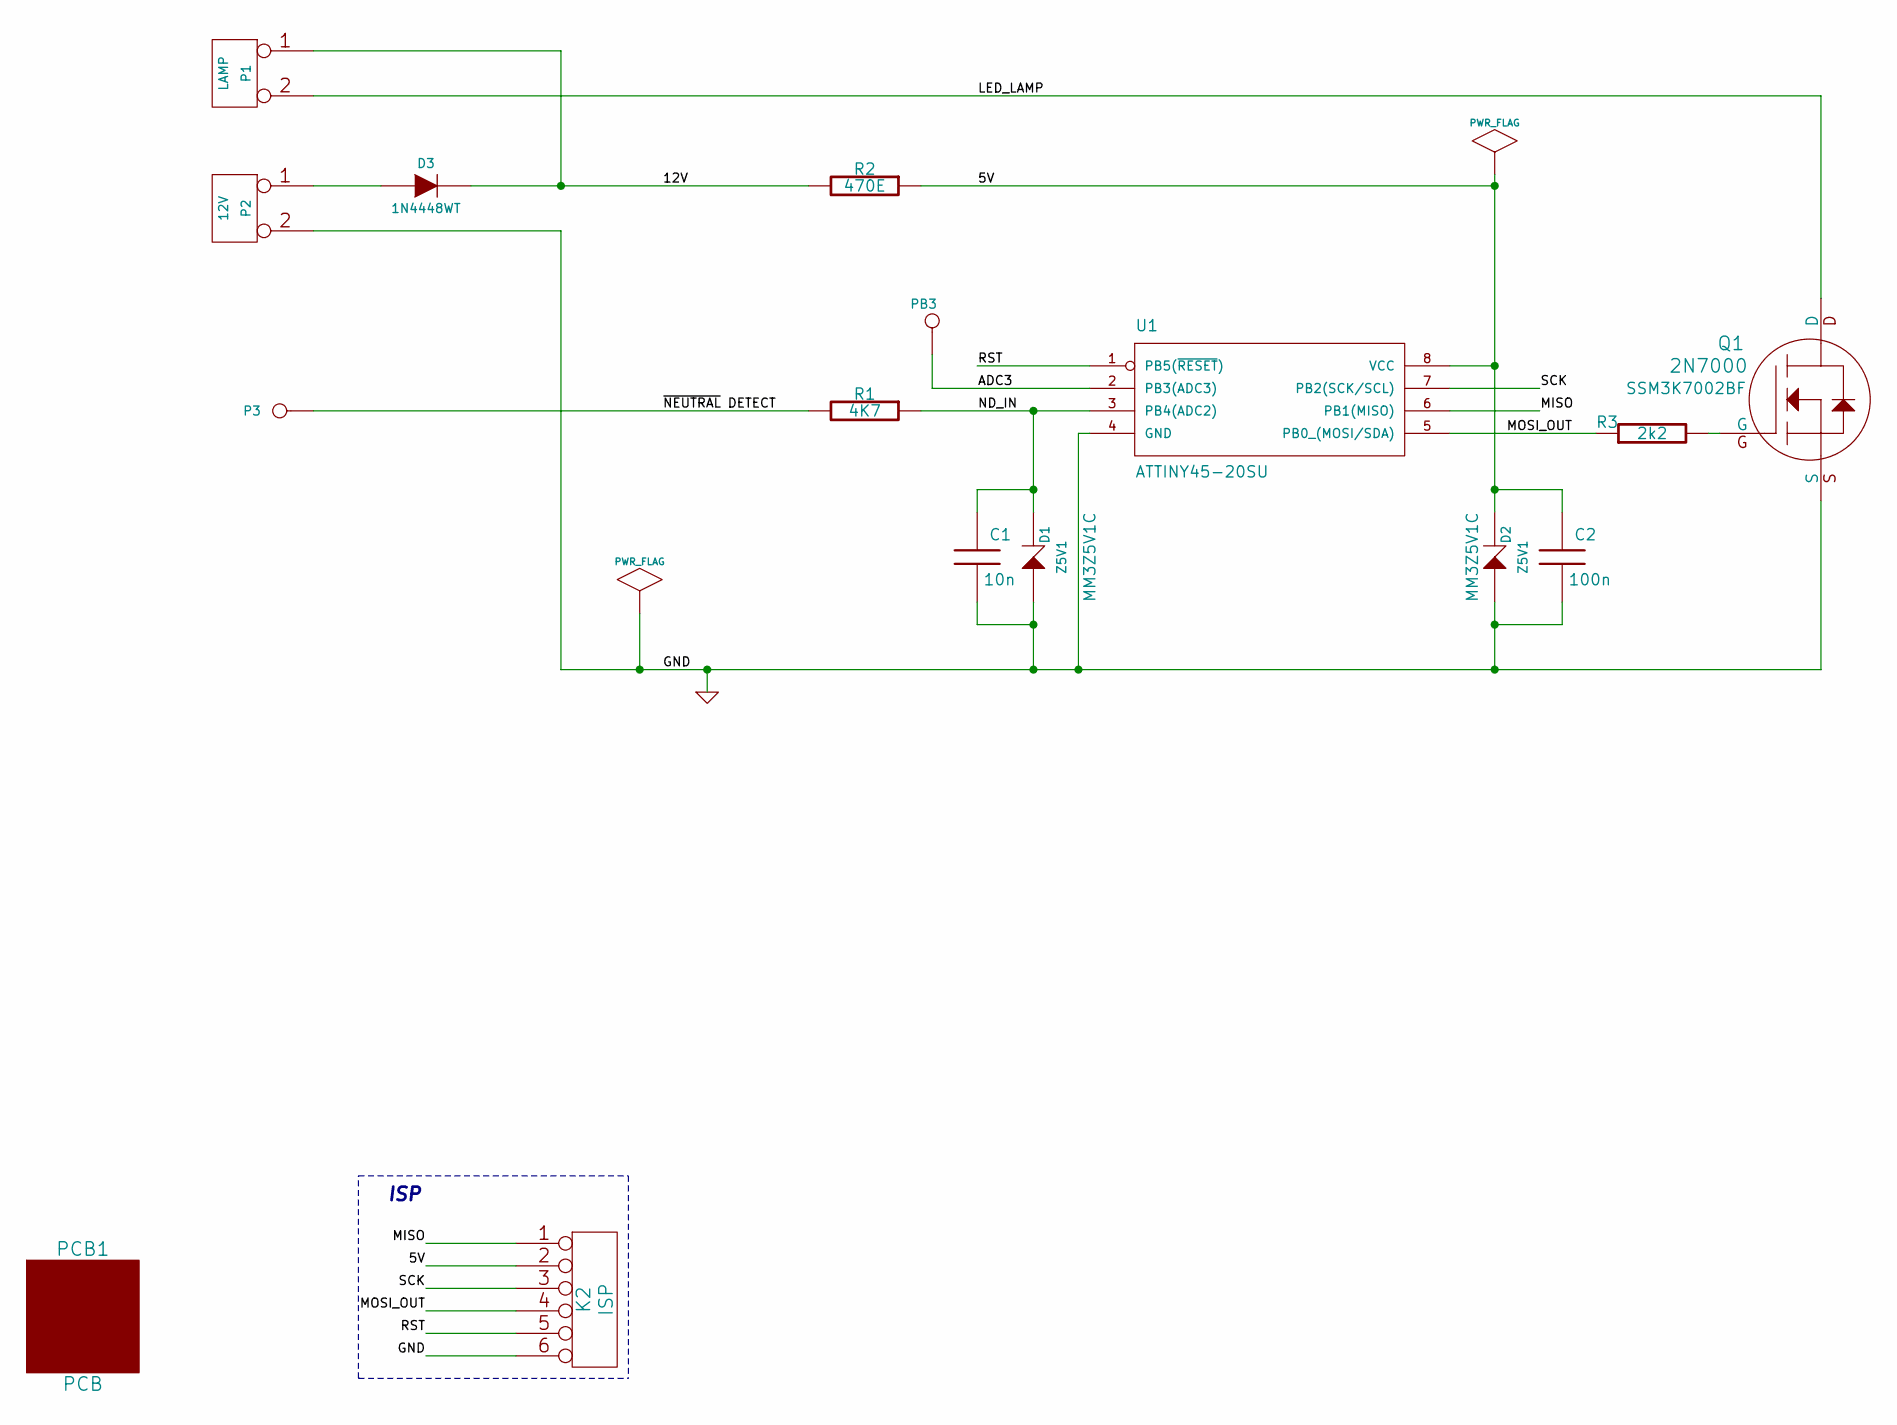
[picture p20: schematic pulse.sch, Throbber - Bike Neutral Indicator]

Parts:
C1: 10n; c_0805
C2: 100n; c_0805
D1, D2: Z5V1; SOD323F
D3: 1N4448WT; SOD523F
K2: ISP; pin_strip_6b
P1: LAMP; pin_strip_2
P2: 12V; Header_12V
P3: ND; Pad01
PB3: ND; Pad01
PCB1: PCB
Q1: 2N7000; SOT23-3
R1: 4K7; r_0805
R2: 470E; r_0805
R3: 2k2; r_0805
U1: ATTINY45-20SU; SO8E

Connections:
/5V: C2.1, D2.2 (K), K2.2, R2.1, U1.8 (VCC)
/12V: D3.2 (K), P1.1, R2.2
/ADC3: PB3.1, U1.2 (PB3(ADC3))
/LED_LAMP: P1.2 (PM), Q1.D
/MISO: K2.1, U1.6 (PB1(MISO))
/MOSI_OUT: K2.4, R3.1, U1.5 (PB0_(MOSI/SDA))
/ND_IN: C1.1, D1.2 (K), R1.1, U1.3 (PB4(ADC2))
/RST: K2.5, U1.1 (PB5(~RESET))
/SCK: K2.3, U1.7 (PB2(SCK/SCL))
/~NEUTRAL_DETECT: P3.1, R1.2
GND: C1.2, C2.2, D1.1 (A), D2.1 (A), K2.6, P2.2 (PM), Q1.S, U1.4 (GND)
unnamed: Q1.G, R3.2
unnamed: D3.1 (A), P2.1

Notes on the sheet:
ISP

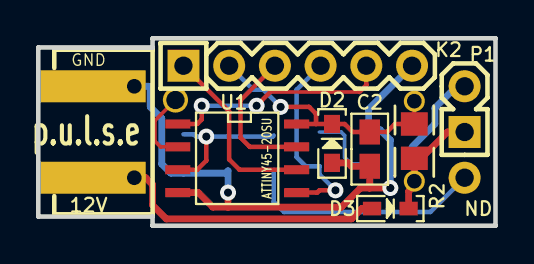
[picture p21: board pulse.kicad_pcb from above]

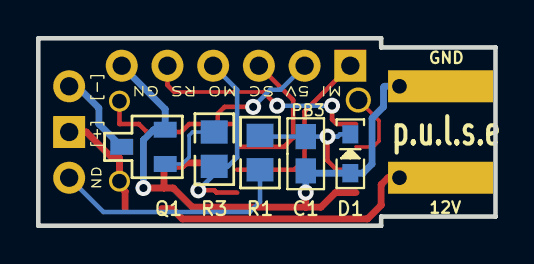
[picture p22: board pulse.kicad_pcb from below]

Board: 2 copper layers, 25.4 x 10.4 mm, 16 parts (5 on the bottom side), 13 nets.

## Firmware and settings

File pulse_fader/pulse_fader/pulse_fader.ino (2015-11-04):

/*
 p.u.l.s.e. Fader for Motorcycle Lamp
 
When NeutralDetect is LOW, Lamp fades via PWM,
When NeutralDetect is HIGH, Lamp is 100% ON
 
 The circuit:
 * LED attached from digital pin 3 (ATMega) 0r pin 0 (ATtiny45) to ground.
 * NeutralDetect Switch to digital pin 4.
 
 Created 23 Jun 2012
 By Anool J Mahidharia
 modified 
 By 
 
 CC By SA License. 
 */

int NeutralDetect = 4;    // NeutralDetect signal to digital pin 4 (ATMega or ATtiny45)
//comment out below line depending on use of ATMega or ATtiny45
//int ledPin = 3;    // LED connected to digital pin 3 (ATMega)

// #define ATMEGA
#define DELAY 1

#ifdef ATMEGA
int ledPin = 3;    // LED connected to digital pin 3 (ATMega)
#else
int ledPin = 0;    // LED connected to digital pin 0 (ATtiny45)
#endif
int brightness = 0;    // how bright the LED is
int fadeAmount1 = 1;    // how many points to fade the LED by
int fadeAmount2 = 4;    // how many points to fade the LED by

void setup()
{ 
    pinMode(NeutralDetect, INPUT);
    pinMode(ledPin, OUTPUT);
}
int count = 0;

void loop(){
  digitalWrite(NeutralDetect, LOW);
  int NDValue = digitalRead(NeutralDetect);
  float val = cos(count++ / 300.) * 127 + 255 - 127;
  if (NDValue == LOW){
    analogWrite(ledPin, (int)val);
  }
  else{
    count = 0;
    digitalWrite(ledPin,HIGH);
  }
  delay(DELAY);
}

void anools_loop()
{
   // read the value of the NeutralDetect pin:
  int NDValue = digitalRead(NeutralDetect);
  
    // if the digital value is low , PWM the LED:
  if (NDValue == LOW)
{ 
  // set the brightness of LED:
  analogWrite(ledPin, brightness);    

  // change the brightness for next time through the loop:
  brightness = brightness + fadeAmount1;

  if (brightness == 224 || brightness == 255) {
  brightness = brightness + fadeAmount2;
  }


  // reverse the direction of the fading at the ends of the fade: 
  if (brightness == 255 || brightness == 224) {
    fadeAmount2 = -fadeAmount2 ; 
  }     

  if (brightness == 223 || brightness == 0) {
    fadeAmount1 = -fadeAmount1 ; 
  }     


  // wait for milliseconds to see the dimming effect    
  delay(10);  
}  
   else
    {
    digitalWrite(ledPin,HIGH);
    }
}

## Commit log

2015-11-04 pushed pulse_v1 from SVN to GIT
    [pulse.brd, pulse.sch, pulse_BoM.ods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]
2015-11-04 changed length to 1 inch
    [pulse-B.Mask.gbs, pulse-B.Paste.gbp, pulse-B.SilkS.gbo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]
